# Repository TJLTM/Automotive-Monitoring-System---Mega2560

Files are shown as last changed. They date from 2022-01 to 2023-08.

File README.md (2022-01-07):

# Automotive-Monitoring-System---Mega2560
OpenSource monitoring system for older vehicles without OBDII. History for this project to give some insight in why i have it designed it as i have. My dad has a 1972 ford bronco that is used to go 4x4ing and it has since the day he bought it new over heated on trails while his friends 1970 stock bronco would be idling behind his vapor locked car on the trail. Mostly this is to solve that problem by providing data. Given data systems can be fixed. I based this on a MEGA2560 because of the number of I/O pins and real time nature of this. I may in the future switch this to SBC based but so far other than a few limitations has worked. 

What is logged: 
1. Fuel Pressure x 2
2. Tempetatures x 6
3. Manifold Vacuum x 2
4. AFR x 2
5. Battery Voltage
6. Current drawn from Alternator 
7. RPM 
8. Oil Pressure
9. GPS Data

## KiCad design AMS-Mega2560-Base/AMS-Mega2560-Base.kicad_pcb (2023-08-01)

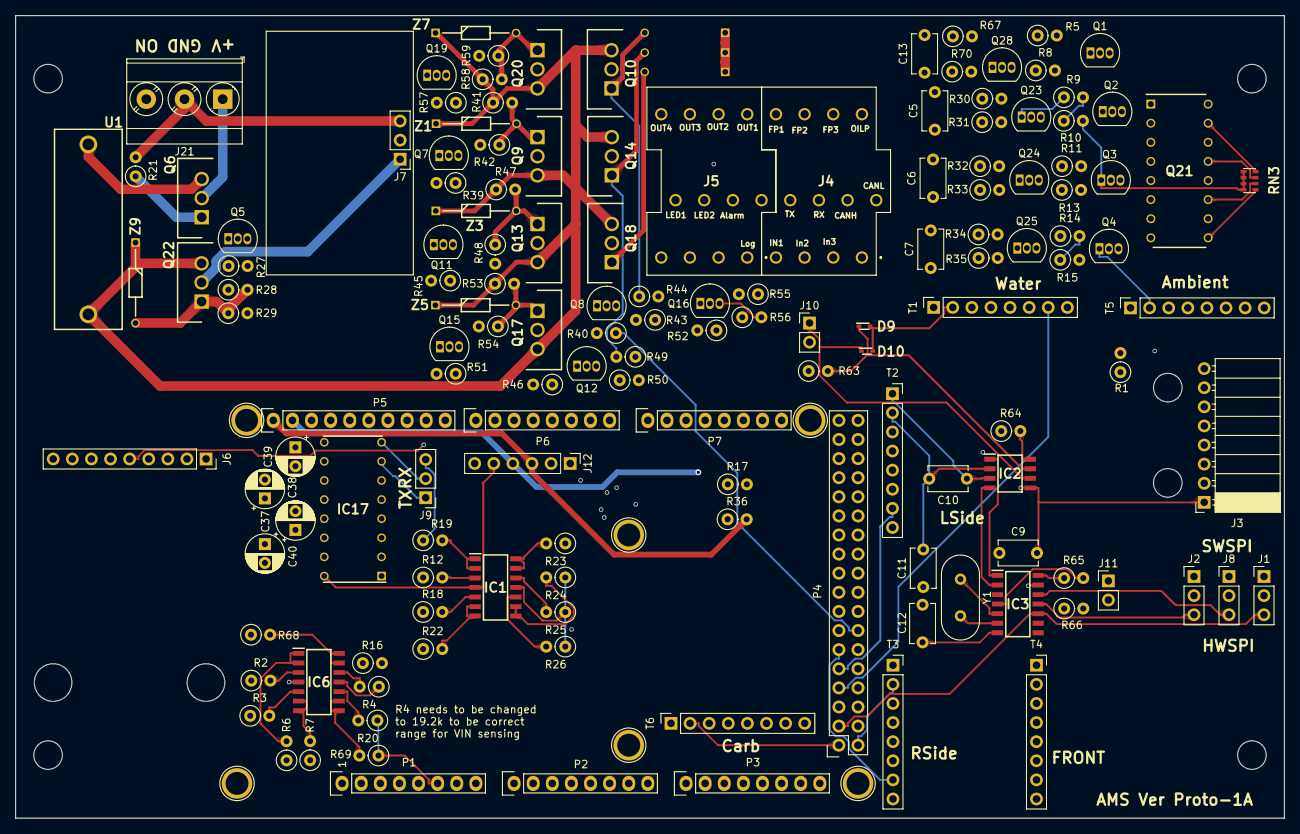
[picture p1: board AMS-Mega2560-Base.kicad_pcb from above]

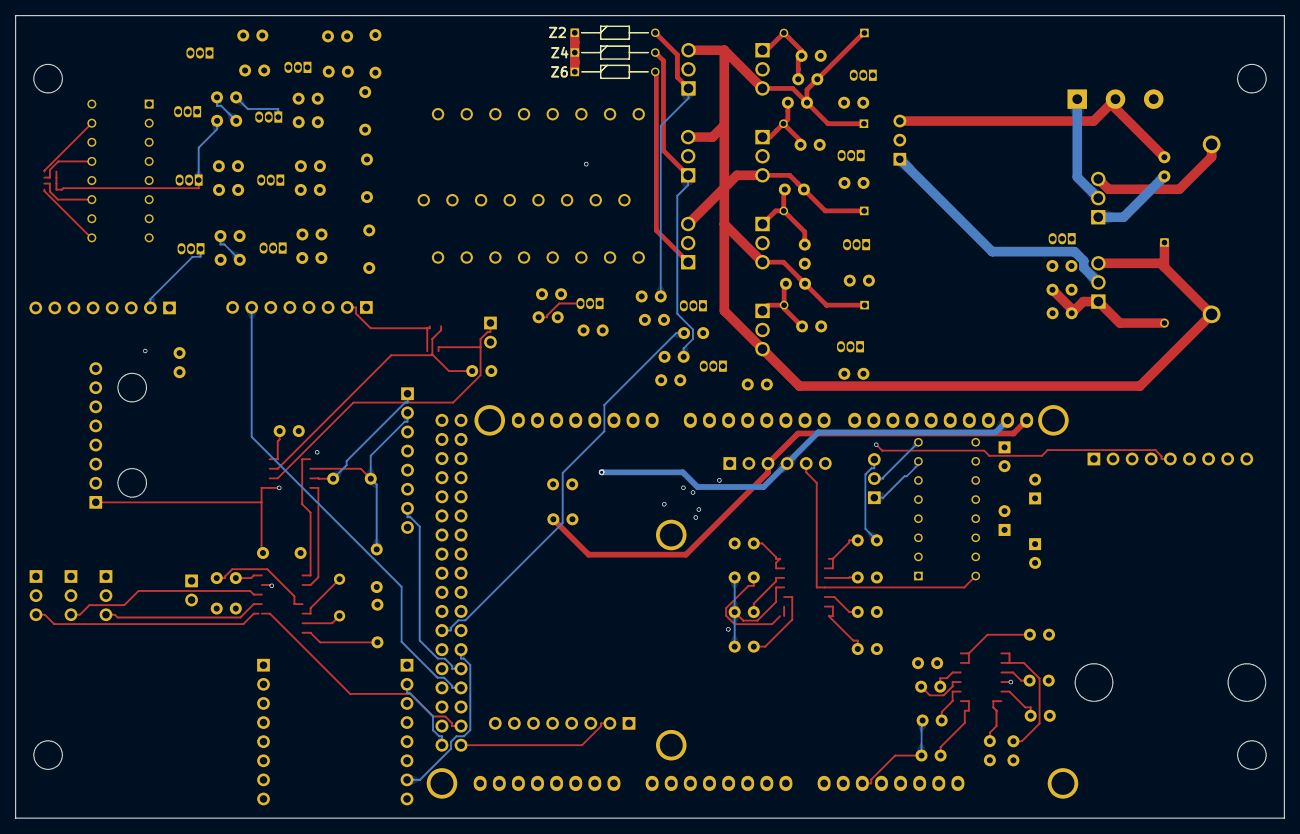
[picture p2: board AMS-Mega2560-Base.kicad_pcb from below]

Board: 4 copper layers, 168.7 x 106.7 mm, 153 parts (3 on the bottom side), 130 nets.

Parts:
C5, C6, C7, C13: 220nF; C_Disc_D5.1mm_W3.2mm_P5.00mm
C9: 0.1uF; C_Disc_D5.1mm_W3.2mm_P5.00mm
C10: 100nF; C_Disc_D5.1mm_W3.2mm_P5.00mm
C11, C12: 22pF; C_Disc_D5.1mm_W3.2mm_P5.00mm
C37, C38, C39, C40: 1uF; CP_Radial_D5.0mm_P2.50mm
D9, D10: ESD5Z5.0T1G; SODFL1608X70N
IC1, IC6: OPA4340UA; SOIC127P600X175-14N
IC2: MCP2542FD-H_SN; SOIC127P600X175-8N
IC3: MCP2518FDT-E_SL; SOIC127P600X175-14N
IC17: MAX232CPE+; DIP762W56P254L1918H457Q16N
J1, J2, J7, J8, J9: Conn_01x03; PinHeader_1x03_P2.54mm_Vertical
J3: Conn_01x08; PinSocket_1x08_P2.54mm_Horizontal
J4: Sense1; 1727751
J5: Sense2; 1727751
J6: AdafruitUltimateGPS; PinSocket_1x09_P2.54mm_Vertical
J10, J11: Conn_01x02; PinHeader_1x02_P2.54mm_Vertical
J12: Conn_01x06; PinHeader_1x06_P2.54mm_Vertical
J21: Screw_Terminal_01x03; TerminalBlock_Phoenix_MKDS-3-3-5.08_1x03_P5.08mm_Horizontal
P1: Power; Socket_Strip_Arduino_1x08
P2, P3: Analog; Socket_Strip_Arduino_1x08
P4: Digital; Socket_Strip_Arduino_2x18
P5: PWM; Socket_Strip_Arduino_1x10
P6: PWM; Socket_Strip_Arduino_1x08
P7: Communication; Socket_Strip_Arduino_1x08
P8, P9, P10, P11, P12, P13: CONN_01X01; Arduino_1pin
Q1, Q2, Q3, Q4, Q5, Q7, Q8, Q11, Q12, Q15, Q16, Q19: 2N7000; TO-92_Inline
Q6, Q9, Q10, Q13, Q14, Q17, Q18, Q20, Q22: IRF9Z34NPBF; TO254P469X1042X1967-3P
Q21: LTV-847; DIP762W60P254L1984H450Q16N
Q23, Q24, Q25, Q28: BS250; TO-92_Inline
R1, R6, R7, R19, R22, R23, R24, R68, R69: 47K; R_Axial_DIN0207_L6.3mm_D2.5mm_P2.54mm_Vertical
R2, R3, R4, R12, R18, R20, R25, R26: 100K; R_Axial_DIN0207_L6.3mm_D2.5mm_P2.54mm_Vertical
R5, R9, R11, R14: 470; R_Axial_DIN0207_L6.3mm_D2.5mm_P2.54mm_Vertical
R8, R10, R13, R15: 5k; R_Axial_DIN0207_L6.3mm_D2.5mm_P2.54mm_Vertical
R16, R65, R66: 47k; R_Axial_DIN0207_L6.3mm_D2.5mm_P2.54mm_Vertical
R17, R36: 2.2k; R_Axial_DIN0207_L6.3mm_D2.5mm_P2.54mm_Vertical
R21: 4.7K; R_Axial_DIN0207_L6.3mm_D2.5mm_P2.54mm_Vertical
R27, R28, R41, R43, R47, R49, R53, R55, R58: 100k; R_Axial_DIN0207_L6.3mm_D2.5mm_P2.54mm_Vertical
R29, R42, R44, R48, R50, R54, R56, R59, R64: 10k; R_Axial_DIN0207_L6.3mm_D2.5mm_P2.54mm_Vertical
R30, R32, R34, R67: 330; R_Axial_DIN0207_L6.3mm_D2.5mm_P2.54mm_Vertical
R31, R33, R35, R70: 1K; R_Axial_DIN0207_L6.3mm_D2.5mm_P2.54mm_Vertical
R39, R40, R45, R46, R51, R52, R57: 1M; R_Axial_DIN0207_L6.3mm_D2.5mm_P2.54mm_Vertical
R63: 120; R_Axial_DIN0207_L6.3mm_D2.5mm_P2.54mm_Vertical
RN3: EXB-38V223JV; EXB38V472JV
T1, T2, T3, T4, T5, T6: Conn_01x08; PinSocket_1x08_P2.54mm_Vertical
U1: BK_HTC-15M
Y1: Crystal; Crystal_HC49-U_Vertical
Z1, Z2, Z3, Z4, Z5, Z6, Z7, Z9: BZX79C10; DIOAD1068W53L380D172

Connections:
+5V: C9.2, C10.1, C40.2, IC1.4 (V+), IC2.3 (VDD), IC2.5 (VIO), IC3.14 (VDD), IC6.4 (V+), IC17.16 (VCC), J3.1, J6.8, J7.2, J12.5, P1.5, Q21.1 (ANODE_1), Q21.3 (ANODE_2), Q21.5 (ANODE_3), Q21.7 (ANODE_4), Q21.10 (COLLECTOR_1), Q21.12 (COLLECTOR_2), Q21.14 (COLLECTOR_3), Q21.16 (COLLECTOR_4), R1.1, R17.1, R36.1, R65.1, T1.1, T2.1, T3.1, T4.1, T5.1, T6.1
+VDC: Q9.3, Q10.3, Q13.3, Q14.3, Q17.3, Q18.3, Q20.3, Q22.3, R28.1, R41.1, R43.1, R47.1, R49.1, R53.1, R55.1, R58.1, U1.2, Z1.1, Z2.1, Z3.1, Z4.1, Z5.1, Z6.1, Z7.1, Z9.1
/BufferedADC1/ADCIN4: IC6.12 (+IN_D), R4.2, R16.2
/CAN Bus/CAN_INT: IC3.4 (~INT), J11.1, R65.2, R66.1
/Sheet6152913C/RSCOM2RX: IC17.8 (R2IN), J9.2
/Sheet6152913C/RSCOM2TX: IC17.7 (T2OUT), J9.1
AmbientCS: P4.15, T5.7
CANCS: IC3.13 (NCS), P4.23
CAN_INT: J11.2, P4.27
CAN_TX_STBY: IC2.8 (STBY), P4.25, R64.2
CarbCS: P4.17, T6.7
Com1RX: IC17.12 (R1OUT), P7.4
Com1TX: IC17.11 (T1IN), P7.3
Com2RX: IC17.9 (R2OUT), P7.6
Com2TX: IC17.10 (T2IN), P7.5
FrontCS: P4.13, T4.7
FuelPressure1: IC6.1 (OUT_A), IC6.2 (-IN_A), P2.3, R6.2
FuelPressure2: IC6.6 (-IN_B), IC6.7 (OUT_B), P2.4, R7.2
FuelPressure3: IC6.8 (OUT_C), IC6.9 (-IN_C), P2.5, R69.2
GND: C5.2, C6.2, C7.2, C9.1, C10.2, C11.2, C12.2, C13.2, C39.1, D9.2, D10.2, IC1.11 (V-), IC2.2 (VSS), IC3.7 (VSS), IC6.11 (V-), IC17.15 (GND), J3.3, J6.7, J7.3, J9.3, J12.6, J21.2, P1.6, P1.7, P4.1, P4.2, P5.4, Q1.1 (S), Q2.1 (S), Q3.1 (S), Q4.1 (S), Q5.1 (S), Q7.1 (S), Q8.1 (S), Q11.1 (S), Q12.1 (S), Q15.1 (S), Q16.1 (S), Q19.1 (S), R2.1, R3.1, R4.1, R6.1, R7.1, R8.2, R10.2, R12.1, R13.2, R15.2, R18.1, R19.1, R20.1, R21.2, R22.1, R23.1, R24.1, R25.1, R26.1, R27.2, R30.2, R32.2, R34.2, R39.2, R40.2, R45.2, R46.2, R51.2, R52.2, R57.2, R64.1, R66.2, R67.2, R68.1, R69.1, RN3.1, RN3.2, RN3.3, RN3.4, T1.2, T2.2, T3.2, T4.2, T5.2, T6.2
GPSBat: J6.3, P2.2
GPSRX: J6.6, P7.1
GPSTX: J6.5, P7.2
IN1TTL: P6.6, Q21.15 (EMITTER_4), RN3.8
IN2TTL: P6.5, Q21.13 (EMITTER_3), RN3.7
IN3TTL: P4.10, Q21.11 (EMITTER_2), RN3.6
Logging: P4.8, Q21.9 (EMITTER_1), RN3.5
LsideCS: P4.9, T2.7
MISO: IC3.11 (SDI), J2.3, J3.5, P4.5
MOSI: IC3.12 (SDO), J3.6, J8.3, P4.6
unnamed: J21.1, Q6.2
unnamed: Q6.3, U1.1
unnamed: C39.2, IC17.6 (V-)
unnamed: C40.1, IC17.2 (V+)
unnamed: IC2.4 (RXD), IC3.2 (RXCAN)
unnamed: IC2.1 (TXD), IC3.1 (TXCAN)
unnamed: C12.1, IC3.6 (OSC1), Y1.2
unnamed: C11.1, IC3.5 (OSC2), Y1.1
unnamed: C37.1, IC17.1 (C1+)
unnamed: C37.2, IC17.3 (C1-)
unnamed: C38.1, IC17.4 (C2+)
unnamed: C38.2, IC17.5 (C2-)
unnamed: J10.2, R63.1
unnamed: Q1.3 (D), R70.1
unnamed: Q1.2 (G), R5.2, R8.1
unnamed: Q2.3 (D), R31.1
unnamed: Q2.2 (G), R9.2, R10.1
unnamed: Q3.3 (D), R33.1
unnamed: Q3.2 (G), R11.2, R13.1
unnamed: Q4.3 (D), R35.1
unnamed: Q4.2 (G), R14.2, R15.1
unnamed: Q5.3 (D), R29.2
unnamed: Q6.1, R21.1
unnamed: Q7.3 (D), R42.2
unnamed: Q8.3 (D), R44.2
unnamed: Q9.1, R41.2, R42.1, Z1.2
unnamed: Q10.1, R43.2, R44.1, Z2.2
unnamed: Q11.3 (D), R48.2
unnamed: Q12.3 (D), R50.2
unnamed: Q13.1, R47.2, R48.1, Z3.2
unnamed: Q14.1, R49.2, R50.1, Z4.2
unnamed: Q15.3 (D), R54.2
unnamed: Q16.3 (D), R56.2
unnamed: Q17.1, R53.2, R54.1, Z5.2
unnamed: Q18.1, R55.2, R56.1, Z6.2
unnamed: Q19.3 (D), R59.2
unnamed: Q20.1, R58.2, R59.1, Z7.2
unnamed: Q21.2 (CATHODE_1), R70.2
unnamed: Q21.4 (CATHODE_2), R31.2
unnamed: Q21.6 (CATHODE_3), R33.2
unnamed: Q21.8 (CATHODE_4), R35.2
unnamed: Q22.1, R28.2, R29.1, Z9.2
unnamed: Q23.1 (D), R9.1
unnamed: Q23.2 (G), R30.1
unnamed: Q24.1 (D), R11.1
unnamed: Q24.2 (G), R32.1
unnamed: Q25.1 (D), R14.1
unnamed: Q25.2 (G), R34.1
unnamed: Q28.1 (D), R5.1
unnamed: Q28.2 (G), R67.1
OUTPUT1: P6.4, Q19.2 (G), R57.1
OUTPUT2: P6.3, Q7.2 (G), R39.1
OUTPUT3: P6.2, Q11.2 (G), R45.1
OUTPUT4: P6.1, Q15.2 (G), R51.1
OUTPUTLED1: P4.14, Q8.2 (G), R40.1
OUTPUTLED2: P4.12, Q12.2 (G), R46.1
OUTPUTSiren: P5.10, Q16.2 (G), R52.1
OilPressure: IC1.1 (OUT_A), IC1.2 (-IN_A), P2.6, R19.2
PowerOn: J21.3, Q5.2 (G), R27.1
RTDMISO: J2.2, T1.5, T2.5, T3.5, T4.5, T5.5, T6.5
RTDMOSI: J8.2, T1.6, T2.6, T3.6, T4.6, T5.6, T6.6
RTDSCLK: J1.2, T1.4, T2.4, T3.4, T4.4, T5.4, T6.4
RsideCS: P4.11, T3.7
SCL: J12.3, P5.1, P7.8, R36.2
SCLK: IC3.10 (SCK), J1.3, J3.4, P4.3
SDA: J12.4, P5.2, P7.7, R17.2
SDCS: J3.7, P4.19
SDDetect: J3.8, P4.21, R1.2
SWMISO: J2.1, P4.32
SWMOSI: J8.1, P4.34
SWSCLK: J1.1, P4.30
Sense1-1: J4.1, P3.2
Sense1-2: D10.1, IC2.6 (CANL), J4.2, J10.1
Sense1-3: IC1.3 (+IN_A), J4.3, R12.2
Sense1-4: C6.1, J4.4, Q24.3 (S)
Sense1-5: D9.1, IC2.7 (CANH), J4.5, R63.2
Sense1-6: IC6.10 (+IN_C), J4.6, R20.2
Sense1-7: C5.1, J4.7, Q23.3 (S)
Sense1-8: IC17.13 (R1IN), J4.8
Sense1-9: IC6.5 (+IN_B), J4.9, R3.2
Sense1-10: C13.1, J4.10, Q28.3 (S)
Sense1-11: IC17.14 (T1OUT), J4.11
Sense1-12: IC6.3 (+IN_A), J4.12, R2.2
Sense2-1: C7.1, J5.1, Q25.3 (S)
Sense2-3: J5.3, Q20.2
Sense2-4: IC1.12 (+IN_D), J5.4, R25.2
Sense2-5: J5.5, Q18.2
Sense2-6: J5.6, Q9.2
Sense2-7: IC1.10 (+IN_C), J5.7, R26.2
Sense2-8: J5.8, Q14.2
Sense2-9: J5.9, Q13.2
Sense2-10: IC1.5 (+IN_B), J5.10, R18.2
Sense2-11: J5.11, Q10.2
Sense2-12: J5.12, Q17.2
SpareADC1: IC1.6 (-IN_B), IC1.7 (OUT_B), P2.7, R22.2
SpareADC2: IC1.8 (OUT_C), IC1.9 (-IN_C), P2.8, R24.2
SpareADC3: IC1.13 (-IN_D), IC1.14 (OUT_D), P3.1, R23.2
VPP: J7.1, Q22.2, R16.1
VoltageSensor: IC6.13 (-IN_D), IC6.14 (OUT_D), P2.1, R68.2
WaterCS: P4.7, T1.7

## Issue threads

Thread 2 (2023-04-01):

Add CAN bus to thie base board.

TJLTM, 2023-04-01:
Add CAN bus to the base board to interface with regular car systems and to move some Sensors and other things offof the base board.

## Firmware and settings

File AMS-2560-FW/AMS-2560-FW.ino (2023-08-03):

#include <Wire.h>
#include <Adafruit_MAX31865.h>
#include <SPI.h>
#include <RTClib.h>
#include <EEPROM.h>


//-----------------------------------------------------------
// Serial Communication
//-----------------------------------------------------------
#define USBSerial Serial
#define RS232P1 Serial1
#define RS232P2 Serial2
char* AcceptedCommands[] = {"UNITS?", "DEVICE?", "BATTERY?", "RTCBATTERY?", "TEMPS?", "UNITTEMP?", "WARNING?",
                            "STREAMING?", "ALLDATA?", "UPDATEALL", "RESETWARNINGS", "RESETALLALARMS",
                            "TIME?", "REBOOT", "RESET", "STREAMINGONBOOT?", "STATUS?", "PORT?", "ALARM?"
                           };
char* ParameterCommands[] = {"SETUNITS", "SETSTREAMINGDATA", "SETTIME", "SETSTREAMINGONBOOT",
                            };
String inputString, inputStringRS232P1, inputStringRS232P2  = "";         // a String to hold incoming data from ports
bool stringComplete, stringCompleteRS232P1, stringCompleteRS232P2 = false;     // whether the string is complete for each respective port
//-----------------------------------------------------------
//-----------------------------------------------------------
// System Level
RTC_DS3231 rtc;
const String DeviceName = "AMS";
const String FWVersion = "0.0.1";
const float ConversionFactor = 5.0 / 1023;
bool WarningActive, AlarmActive = false;
int TotalWarnings = 7;
int ArrayOfWarnings[] = {};
long TempTimer, WarningBlinkTimer;
bool StreamingDataUSB, StreamingDataRS232 = false;
char Units;
String TempUnits, PressureUnits;
//-----------------------------------------------------------
/*
   All the Stored Values and Times to have states
   that can be recalled if streaming is turned off
*/
//Fuel Pressure
float LastFuel1, LastFuel2 = 0.0;
String LastTimeFuel = "";
//Battery Monitoring
float LastDCVoltage, LastGPSVoltage = 0.0;
String LastTimeDCVoltage, LastTimeGPSVoltage = "";
// Temps
String LastTimeTemp = "";
float LastCarbTemp, LastAmbientTemp, LastFrontOfEngineTemp, LastRightSideTemp, LastLeftSideTemp, LastWaterTemp = 0.0;
float LastRTCTemp = 0.0;
String LastTimeRTCTemp = "";
//-----------------------------------------------------------
//-----------------------------------------------------------
//RTD sensors
#define RTDWaterCS 48
#define RTDCarbCS 38
#define RTDAmbientCS 40
#define RTDLSCS 46
#define RTDRSCS 44
#define RTDFrontCS 42
#define RREF      430.0
#define RNOMINAL  100.0
Adafruit_MAX31865 RTDWater = Adafruit_MAX31865(RTDWaterCS);
Adafruit_MAX31865 RTDCarb = Adafruit_MAX31865(RTDCarbCS);
Adafruit_MAX31865 RTDAmbient = Adafruit_MAX31865(RTDAmbientCS);
Adafruit_MAX31865 RTDLS = Adafruit_MAX31865(RTDLSCS);
Adafruit_MAX31865 RTDRS = Adafruit_MAX31865(RTDRSCS);
Adafruit_MAX31865 RTDFront = Adafruit_MAX31865(RTDFrontCS);
//-----------------------------------------------------------
//-----------------------------------------------------------
//Alarm
#define AlarmOut 8
#define LED1 43
#define LED2 45
//-----------------------------------------------------------
//-----------------------------------------------------------
// Spare Inputs Outputs and Analog
#define LoggingInput 49
#define SpareInput1 2
#define SpareInput2 3
#define SpareInput3 47

#define SpareOutput1 4
#define SpareOutput2 5
#define SpareOutput3 6
#define SpareOutput4 7
//-----------------------------------------------------------
//-----------------------------------------------------------
// ADC Sensors
#define FuelPressure1Pin A2
#define FuelPressure2Pin A3
#define FuelPressure3Pin A4
#define VoltageSensorPin A0
#define OilPressurePin A5
#define GPSBattPin A1
#define SpareBufferedADC1Pin A6
#define SpareBufferedADC2Pin A7
#define SpareBufferedADC3Pin A8
#define SpareRAWADC1Pin A9
//-----------------------------------------------------------
//-----------------------------------------------------------
#define SDCardDetectPin 34
#define SDCS 36


void setup() {
  rtc.begin();
  RS232P1.begin(115200);
  RS232P2.begin(115200);
  USBSerial.begin(115200);
  inputString.reserve(100);
  inputStringRS232P1.reserve(100);
  inputStringRS232P2.reserve(100);

  pinMode(AlarmOut, OUTPUT);
  pinMode(LED1, OUTPUT);
  pinMode(LED2, OUTPUT);


  //RTD
  pinMode(RTDWaterCS, OUTPUT);
  pinMode(RTDCarbCS, OUTPUT);
  pinMode(RTDAmbientCS, OUTPUT);
  pinMode(RTDLSCS, OUTPUT);
  pinMode(RTDRSCS, OUTPUT);
  pinMode(RTDFrontCS, OUTPUT);
  /*
      Please Reference Adafruit_MAX31865
      docs for setup of these boards if
      you are going to use 4 or 2 wire
  */
  RTDWater.begin(MAX31865_3WIRE);
  RTDCarb.begin(MAX31865_3WIRE);
  RTDAmbient.begin(MAX31865_3WIRE);
  RTDLS.begin(MAX31865_3WIRE);
  RTDRS.begin(MAX31865_3WIRE);
  RTDFront.begin(MAX31865_3WIRE);

  //Energy
  //Load from EEProm

  //Load Streaming Setting from EEProm
  StreamingDataUSB = GetFromEEPROMStreamOnBootUSB();
  StreamingDataRS232 = GetFromEEPROMStreamOnBootRS232();

  //load system settings from EEProm

  //Set Warning Array up with -1 for being cleared.
  ResetWarnings();

  //Set up displays and output on the Serial Port
  BroadCast("Starting " + DeviceName);
  BroadCast("FW: " + FWVersion);
  Units = GetFromEEPROMUnits();
  SetUnitsForOutput();
  BroadCast("Units: " + String(Units));

  //Run through the sensors and get values for everything
  ForceCompleteUpdateOfAllStates();
  BroadCast("System Initialized and values populated:" + GetCurrentTime());
}

void loop() {

  /*
    Handle the Incoming commands from the Serial Ports
    after all the other operations have been done
  */
  if (stringComplete) {
    inputString = PainlessInstructionSet(inputString, 0);
    stringComplete = false;
  }

  serialRS232P1();
  if (stringCompleteRS232P1) {
    stringCompleteRS232P1 = PainlessInstructionSet(inputStringRS232P1, 1);
    stringCompleteRS232P1 = false;
  }

  serialRS232P2();
  if (stringCompleteRS232P2) {
    stringCompleteRS232P2 = PainlessInstructionSet(inputStringRS232P2, 1);
    stringCompleteRS232P2 = false;
  }

  SensorData();
}

void SensorData(){
  
}

void FuelPressure() {
  float FuelPressureDN1 = ReadAnalog(25, FuelPressure1Pin);
  float FuelPressureDN2 = ReadAnalog(25, FuelPressure2Pin);
  float FuelPressureDN3 = ReadAnalog(25, FuelPressure3Pin);

  //Sensors i'm using drop out at .5 volts and anything below that will show neg pressure. DN 102 translates to 0.5V
  if (FuelPressureDN1 > 102) {
    if (Units == 'I') {
      LastFuel1 = (7.5 * ConversionFactor * FuelPressureDN1) - 3.75;
      LastFuel2 = (7.5 * ConversionFactor * FuelPressureDN2) - 3.75;
    }
    else {
      LastFuel1 = ConvertPSItoKPa((7.5 * ConversionFactor * FuelPressureDN1) - 3.75);
      LastFuel2 = ConvertPSItoKPa((7.5 * ConversionFactor * FuelPressureDN2) - 3.75);
    }
  }
  else {
    LastFuel1, LastFuel2 = 0.0;
  }

  LastTimeFuel = GetCurrentTime();
}

void RTDSensors() {
  uint16_t rtd0 = RTDWater.readRTD();
  if (Units == 'I') {
    LastWaterTemp = ConvertCtoF(RTDWater.temperature(RNOMINAL, RREF));
  }
  else {
    LastWaterTemp = RTDWater.temperature(RNOMINAL, RREF);
  }

  uint16_t rtd1 = RTDCarb.readRTD();
  if (Units == 'I') {
    LastCarbTemp = ConvertCtoF(RTDCarb.temperature(RNOMINAL, RREF));
  }
  else {
    LastCarbTemp = RTDCarb.temperature(RNOMINAL, RREF);
  }

  uint16_t rtd2 = RTDAmbient.readRTD();
  if (Units == 'I') {
    LastAmbientTemp = ConvertCtoF(RTDAmbient.temperature(RNOMINAL, RREF));
  }
  else {
    LastAmbientTemp = RTDAmbient.temperature(RNOMINAL, RREF);
  }

  uint16_t rtd3 = RTDLS.readRTD();
  if (Units == 'I') {
    LastRightSideTemp = ConvertCtoF(RTDLS.temperature(RNOMINAL, RREF));
  }
  else {
    LastRightSideTemp = RTDLS.temperature(RNOMINAL, RREF);
  }

  uint16_t rtd4 = RTDLS.readRTD();
  if (Units == 'I') {
    LastLeftSideTemp = ConvertCtoF(RTDLS.temperature(RNOMINAL, RREF));
  }
  else {
    LastLeftSideTemp = RTDLS.temperature(RNOMINAL, RREF);
  }

  uint16_t rtd5 = RTDFront.readRTD();
  if (Units == 'I') {
    LastFrontOfEngineTemp = ConvertCtoF(RTDFront.temperature(RNOMINAL, RREF));
  }
  else {
    LastFrontOfEngineTemp = RTDFront.temperature(RNOMINAL, RREF);
  }

  LastTimeTemp = GetCurrentTime();
}


//------------------------------------------------------------------
//Other sensors
//------------------------------------------------------------------
void ReadBatteryVoltages() {
  float DCVoltageDN = ReadAnalog(50, VoltageSensorPin);
  float GPSVoltageDN = ReadAnalog(50, GPSBattPin);

  LastDCVoltage = 3.8 * ConversionFactor * DCVoltageDN - 1.2;
  LastTimeDCVoltage = GetCurrentTime();

  LastGPSVoltage = ConversionFactor * GPSVoltageDN;
  LastTimeGPSVoltage = LastTimeDCVoltage;

  if (LastDCVoltage < 10.5) {
    AddWarningToList(5);
  }

  if (LastGPSVoltage < 2.3) {
    AddWarningToList(1);
  }
}


//------------------------------------------------------------------
//EEPROM functions
//------------------------------------------------------------------
int GetFromEEPROMStreamOnBootUSB() {
  int Value = EEPROM.read(4);
  if (0 > Value || Value >= 2) {
    Value = 0;
    EEPROM.update(4, Value);
  }
  return Value;
}

int GetFromEEPROMStreamOnBootRS232() {
  int Value = EEPROM.read(5);
  if (0 > Value || Value >= 2) {
    Value = 0;
    EEPROM.update(5, Value);
  }
  return Value;
}

char GetFromEEPROMUnits() {
  char Value = EEPROM.read(0);
  if (Value != 'I' && Value != 'M') {
    Value = 'I';
    EEPROM.update(0, Value);
  }
  return Value;
}

//------------------------------------------------------------------
//Helper functions
//------------------------------------------------------------------
void(* resetFunc) (void) = 0;  // declare reset fuction at address 0

String StatesForOutput(int State) {
  String Value = "Off";
  if (State == 1) {
    Value = "On";
  }
  return Value;
}

void RebootDisBitch() {
  BroadCast("%R," + GetCurrentTime() + ",Rebooting");
  delay(2000);
  resetFunc();
}

void MIBFLASH() {
  BroadCast("%R," + GetCurrentTime() + ",Reseting wait for reboot Message");
  for (int i = 0 ; i < EEPROM.length() ; i++) {
    EEPROM.write(i, 0);
  }
  RebootDisBitch();
}

float ConvertCtoF(float C) {
  float F = (1.8 * C) + 32;
  return F;
}

float ConvertPSItoKPa(float PSI) {
  float KPA = 6.8947572932 * PSI;
  return KPA;
}

String GetCurrentTime() {
  DateTime now = rtc.now();

  char buf1[20];
  sprintf(buf1, "%02d:%02d:%02d-%02d/%02d/%02d",  now.hour(), now.minute(), now.second(), now.day(), now.month(), now.year());

  LastTimeRTCTemp = buf1;
  if (Units == 'I') {
    LastRTCTemp = ConvertCtoF(rtc.getTemperature());
  }
  else {
    LastRTCTemp = rtc.getTemperature();
  }
  return buf1;
}

String GetCurrentDate() {
  DateTime now = rtc.now();
  String CurrentDate = String(now.year()) + String(now.month()) + String(now.day());
  return CurrentDate;
}

void SetUnitsForOutput() {
  if (Units == "M") {
    TempUnits = "C";
    PressureUnits = "KPa";
  }
  else {
    TempUnits = "F";
    PressureUnits = "PSI";
  }
}

float ReadAnalog(int Samples, int PinNumber) {
  long Sum = 0;
  float Value = 0;
  for (int x = 0; x < Samples; x++) {
    Sum = Sum + analogRead(PinNumber);
  }
  Value = (Sum / Samples);
  return Value;
}

void PressureSensors() {
  int Samples = 50;
  long FuelSum = 0;
  long FuelSum1 = 0;
  long OilSum = 0;
  for (int x = 0; x < Samples; x++) {
    FuelSum = FuelSum + analogRead(FuelPressureSensorsPinAtCarb);
    FuelSum1 = FuelSum1 + analogRead(FuelPressureSensorsPinBeforeCooler);
    OilSum = OilSum + analogRead(OilPressureSensorsPin);
    
  }

  float FuelPSIatCarb = 1.2 * 7.5 * ConversionFactor * (FuelSum / Samples);
  float FuelPSIatPump = 1.2 * 7.5 * ConversionFactor * (FuelSum1 / Samples);
  float OilPSI = 25 * ConversionFactor * (OilSum / Samples) - 12.5;
  FuelPressureWarning(FuelPSIatCarb);

  
  float FuelPressure_carb = 0.0;
  float FuelPressure_pump = 0.0;
  float OilPressure = 0.0;
  String Units = "PSI";
  if (Units == "M") {
    FuelPressure_carb = ConvertPSItoKPa(FuelPSIatCarb);
    FuelPressure_pump = ConvertPSItoKPa(FuelPSIatPump);
    OilPressure = ConvertPSItoKPa(OilPSI);
    Units = "KPa";
  }
  else {
    FuelPressure_carb = FuelPSIatCarb;
    FuelPressure_pump = FuelPSIatPump;
    OilPressure = OilPSI;
  }

  LastFuelPatCarb = FuelPressure_carb;
  LastFuelPatPump = FuelPressure_pump;
  String LogEntry = "Units," + Units + ",Fuel At Carb," + String(FuelPressure_carb) + ",Fuel At pump," + String(FuelPressure_pump) + ",Oil," + String(OilPressure);
  AddLogEntry(0, "Pressure Sensors", LogEntry);
}

void ForceCompleteUpdateOfAllStates() {

  ReadBatteryVoltages();
}
//------------------------------------------------------------------
//Serial
//------------------------------------------------------------------
/*
  SerialEvent occurs whenever a new data comes in the hardware serial RX. This
  routine is run between each time loop() runs, so using delay inside loop can
  delay response. Multiple bytes of data may be available.
*/
void serialEvent() {
  while (USBSerial.available()) {
    // get the new byte:
    char inChar = (char)USBSerial.read();
    // add it to the inputString:
    inputString += inChar;
    // if the incoming character is a carriage return, set a flag so the main loop can
    // do something about it:
    if (inChar == '\r') {
      stringComplete = true;
    }
  }
}

void serialRS232P1() {
  while (RS232P1.available()) {
    // get the new byte:
    char inChar = (char)RS232P1.read();
    // add it to the inputString:
    inputStringRS232P1 += inChar;
    // if the incoming character is a carriage return, set a flag so the main loop can
    // do something about it:
    if (inChar == '\r') {
      stringCompleteRS232P1 = true;
    }
  }
}

void serialRS232P2() {
  while (RS232P2.available()) {
    // get the new byte:
    char inChar = (char)RS232P2.read();
    // add it to the inputString:
    inputStringRS232P2 += inChar;
    // if the incoming character is a carriage return, set a flag so the main loop can
    // do something about it:
    if (inChar == '\r') {
      stringCompleteRS232P2 = true;
    }
  }
}

void BroadCast(String Message) {
  SendItOut(Message, 0);
  SendItOut(Message, 1);
  SendItOut(Message, 2);
}

void CurrentSerialPort(int WhichPort) {
  if (WhichPort == 0) {
    USBSerial.println("%R,Current Port,USB");
  }
  if (WhichPort == 1) {
    RS232P1.println("%R,Current Port,USB");
  }
  if (WhichPort == 2) {
    RS232P2.println("%R,Current Port,USB");
  }

}

void SendItOut(String Message, int WhichPort) {
  if (WhichPort == 0) {
    USBSerial.println(Message);
  }
  if (WhichPort == 1) {
    RS232P1.println(Message);
  }
  if (WhichPort == 2) {
    RS232P2.println(Message);
  }
}

//------------------------------------------------------------------
//Serial Output
//------------------------------------------------------------------
void OutputAllData(int WhichPort) {
  GetDeviceInfo(WhichPort);
  GetSystemTime(WhichPort);
  AllWarningMessages(WhichPort);
  GetStreamingState(WhichPort);
  GetUnits(WhichPort);
  GetDCBatteryVoltage(WhichPort);
  GetRTCBatteryVotlage(WhichPort);
  GetHeadUnitTemp(WhichPort);
  GetStreamingOnBoot(WhichPort);
  GetStreamingState(WhichPort);
}

void OutputLiveData(int WhichPort) {
  GetDCBatteryVoltage(WhichPort);
  GetRTCBatteryVotlage(WhichPort);
  GetHeadUnitTemp(WhichPort);
  GetStreamingOnBoot(WhichPort);
  GetStreamingState(WhichPort);
}

void GetDCBatteryVoltage(int WhichPort) {
  SendItOut("%R," + LastTimeDCVoltage + ",VDC," + LastDCVoltage, WhichPort);
}

void GetRTCBatteryVotlage(int WhichPort) {
  SendItOut("%R," + LastTimeRTCVoltage + ",RTCBattery," + LastRTCVoltage, WhichPort);
}

void GetHeadUnitTemp(int WhichPort) {
  SendItOut("%R," + LastTimeRTCTemp + ",Head Unit Temp,Units," + TempUnits + "," + LastRTCTemp, WhichPort);
}

void GetUnits(int WhichPort) {
  SendItOut("%R,Units," + String(Units), WhichPort);
}

void GetDeviceInfo(int WhichPort) {
  SendItOut("%R," + DeviceName + "," + FWVersion, WhichPort);
}

void GetStreamingState(int WhichPort) {
  SendItOut("%R,StreamingData,USB," + StatesForOutput(StreamingDataUSB) + ",RS232," +
            StatesForOutput(StreamingDataRS232) , WhichPort);
}

void GetSystemTime(int WhichPort) {
  SendItOut("%R,System Time," + GetCurrentTime(), WhichPort);
}

void GetStreamingOnBoot(int WhichPort) {
  SendItOut("%R,Streaming Data on boot,USB," + StatesForOutput(GetFromEEPROMStreamOnBootUSB()) + ",RS232," +
            StatesForOutput(GetFromEEPROMStreamOnBootRS232()) , WhichPort);
}

void GetAlarmStatus(int WhichPort) {
  String Message = "%R," + GetCurrentTime() + ",ALARM,Cleared";
  if (AlarmActive == true) {
    Message = "%R," + GetCurrentTime() + ",ALARM,Active";
  }
  SendItOut(Message, WhichPort);
}

void GetTemps(int WhichPort) {
  SendItOut("%R,Temps,Units," + "" + ",Water," + String(LastWaterTemp) + ",," + String(LastCarbTemp) + ",," + String(LastAmbientTemp) , WhichPort);
}
//------------------------------------------------------------------
//Alarm and Warnings
//------------------------------------------------------------------
void Error(int Number, int WhichPort) {
  const char* Errors[] = {"command not recognized", "command Parameter out of range", "command not supported on this platform",
                          "command can not be processed", "Invalid Parameter", "Invalid Command Format"
                         };
  SendItOut("%R,Error," + String(Errors[Number]), WhichPort);
}

void Warning() {
  if (WarningActive == true) {
    if (abs(millis() - WarningBlinkTimer) >  333) {
      WarningBlinkTimer = millis();
      if (digitalRead(WarningLED) == LOW) {
        digitalWrite(WarningLED, HIGH);
      } else {
        digitalWrite(WarningLED, LOW);
      }
    }
  }
}

void AddWarningToList(int WarningID) {
  WarningActive = true;
  if (ArrayOfWarnings[WarningID] != WarningID) {
    ArrayOfWarnings[WarningID] = WarningID;
    OutputWarningMessage(WarningID);
  }
}

void OutputWarningMessage(int ID) {
  if (ArrayOfWarnings[ID] != 0) {
    String Message = "";
    switch (ID) {
      case 1:
        Message = "RTC Battery voltage is low";
        break;
      case 2:
        Message = "One of the holding tanks is getting full";
        break;
      case 3:
        Message = "";
        break;
      case 4:
        Message = "";
        break;
      case 5:
        Message = "Battery voltage is low";
        break;
      case 6:
        Message = "";
        break;
      case 7:
        Message = "";
        break;
    }
    BroadCast("%R,Warning," + Message);
  }
}

void AllWarningMessages(int WhichPort) {
  if (WarningActive == true) {
    for (int i = 1; i <= TotalWarnings; i++) {
      if (ArrayOfWarnings[i] != -1) {
        OutputWarningMessage(i);
        WarningActive = true;
      }
    }
  }
  else {
    SendItOut("%R,Warning,Clear", WhichPort);
  }
}

void ALARM() {
  digitalWrite(AlarmOut, HIGH);
  AlarmActive = true;
  GetAlarmStatus(0);
  GetAlarmStatus(1);
  GetAlarmStatus(2);
}

void ResetAlarm() {
  digitalWrite(AlarmOut, LOW);
  if (AlarmActive == true) {
    AlarmActive = false;
    GetAlarmStatus(0);
    GetAlarmStatus(1);
  }
}

void ResetWarnings() {
  for (int i = 1; i <= TotalWarnings; i++) {
    ArrayOfWarnings[i] = -1;
  }
  WarningActive = false;
  digitalWrite(WarningLED, LOW);
}

void ResetAllAlarmsAndWarnings() {
  ResetAlarm();
  ResetWarnings();
}
//------------------------------------------------------------------
//Commands
//------------------------------------------------------------------
void SetUnits(String Value, int WhichPort) {
  char CurrentUnits = Units;
  int Index = Value.indexOf("*");
  int End = Value.indexOf("\r");
  String ThingToTest = Value.substring(Index + 1, End - 1);
  if (ThingToTest.length() == 1) {
    bool CorrectParam = false;
    if (ThingToTest == "I") {
      Units = 'I';
      CorrectParam = true;
    }
    if (ThingToTest == "M") {
      Units = 'M';
      CorrectParam = true;
    }
    if (CorrectParam == true) {
      EEPROM.update(0, Units);
      GetUnits(WhichPort);
      if (CurrentUnits != Units) {
        ForceCompleteUpdateOfAllStates();
      }
    }
    else {
      Error(4, WhichPort);
    }
  }
  else {
    Error(1, WhichPort);
  }
  SetUnitsForOutput();
}

void SetStreamingData(String Value, int WhoToSet, int WhichPort) {
  int Index = Value.indexOf("*");
  int End = Value.indexOf("\r");
  String Start = Value.substring(Index + 1, End - 1);
  int SecondParam = Start.indexOf("*");
  String SerialPortName  = Start.substring(0, SecondParam);
  String State = Start.substring(SecondParam + 1, End - 1);
  bool CorrectParam = false;
  if (SerialPortName == "USB") {
    if (State == "OFF") {
      if (WhoToSet == 1) {
        EEPROM.update(4, 0);
      }
      StreamingDataUSB = false;
      CorrectParam = true;
    }
    if (State == "ON") {
      if (WhoToSet == 1) {
        EEPROM.update(4, 1);
      }
      StreamingDataUSB = true;
      CorrectParam = true;
    }
  }

  if (SerialPortName == "RS232") {
    if (State == "OFF") {
      if (WhoToSet == 1) {
        EEPROM.update(5, 0);
      }
      StreamingDataRS232 = false;
      CorrectParam = true;
    }
    if (State == "ON") {
      if (WhoToSet == 1) {
        EEPROM.update(5, 1);
      }
      StreamingDataRS232 = true;
      CorrectParam = true;
    }
  }

  if (CorrectParam == true) {
    if (WhoToSet == 1) {
      GetStreamingOnBoot(WhichPort);
    }
    GetStreamingState(WhichPort);
  }
  else {
    Error(4, WhichPort);
  }
}
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

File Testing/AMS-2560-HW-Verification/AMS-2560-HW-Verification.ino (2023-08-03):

#include <Wire.h>
#include <Adafruit_MAX31865.h>
#include <SPI.h>
#include <RTClib.h>


//-----------------------------------------------------------
// Serial Communication
//-----------------------------------------------------------
#define USBSerial Serial
#define RS232P1 Serial1
#define RS232P2 Serial2

String inputStringP1 = "";         // a String to hold incoming data
bool stringCompleteP1 = false;  // whether the string is complete
String inputStringP2 = "";         // a String to hold incoming data
bool stringCompleteP2 = false;  // whether the string is complete

//-----------------------------------------------------------
//-----------------------------------------------------------
// System Level
RTC_DS3231 rtc;
const float ConversionFactor = 5.0 / 1023;
//RTD sensors
#define RTDWaterCS 48
#define RTDCarbCS 38
#define RTDAmbientCS 40
#define RTDLSCS 46
#define RTDRSCS 44
#define RTDFrontCS 42
#define RREF      430.0
#define RNOMINAL  100.0
Adafruit_MAX31865 RTDWater = Adafruit_MAX31865(RTDWaterCS);
Adafruit_MAX31865 RTDCarb = Adafruit_MAX31865(RTDCarbCS);
Adafruit_MAX31865 RTDAmbient = Adafruit_MAX31865(RTDAmbientCS);
Adafruit_MAX31865 RTDLS = Adafruit_MAX31865(RTDLSCS);
Adafruit_MAX31865 RTDRS = Adafruit_MAX31865(RTDRSCS);
Adafruit_MAX31865 RTDFront = Adafruit_MAX31865(RTDFrontCS);
//-----------------------------------------------------------
//-----------------------------------------------------------
//Alarm
#define AlarmOut 8
#define LED1 43
#define LED2 45
//-----------------------------------------------------------
//-----------------------------------------------------------
// Spare Inputs Outputs and Analog
#define LoggingInput 49
#define SpareInput1 2
#define SpareInput2 3
#define SpareInput3 47

#define SpareOutput1 4
#define SpareOutput2 5
#define SpareOutput3 6
#define SpareOutput4 7
//-----------------------------------------------------------
//-----------------------------------------------------------
// ADC Sensors
#define FuelPressure1Pin A2
#define FuelPressure2Pin A3
#define FuelPressure3Pin A4
#define VoltageSensorPin A0
#define OilPressurePin A5
#define GPSBattPin A1
#define SpareBufferedADC1Pin A6
#define SpareBufferedADC2Pin A7
#define SpareBufferedADC3Pin A8
#define SpareRAWADC1Pin A9
//-----------------------------------------------------------
//-----------------------------------------------------------
#define SDCardDetectPin 34
#define SDCS 36

void setup() {
  rtc.begin();
  
  // reserve 200 bytes for the inputString:
  inputStringP1.reserve(200);
  inputStringP2.reserve(200);
  
  RS232P1.begin(115200);
  RS232P2.begin(115200);
  USBSerial.begin(115200);

  pinMode(AlarmOut, OUTPUT);
  pinMode(LED1, OUTPUT);
  pinMode(LED2, OUTPUT);

  pinMode(SpareInput1, INPUT);
  pinMode(SpareInput2, INPUT);
  pinMode(SpareInput3, INPUT);
  pinMode(LoggingInput, INPUT);

  pinMode(SDCardDetectPin, INPUT);

  //RTD
  pinMode(RTDWaterCS, OUTPUT);
  pinMode(RTDCarbCS, OUTPUT);
  pinMode(RTDAmbientCS, OUTPUT);
  pinMode(RTDLSCS, OUTPUT);
  pinMode(RTDRSCS, OUTPUT);
  pinMode(RTDFrontCS, OUTPUT);
  /*
      Please Reference Adafruit_MAX31865
      docs for setup of these boards if
      you are going to use 4 or 2 wire
  */
  RTDWater.begin(MAX31865_3WIRE);
  RTDCarb.begin(MAX31865_3WIRE);
  RTDAmbient.begin(MAX31865_3WIRE);
  RTDLS.begin(MAX31865_3WIRE);
  RTDRS.begin(MAX31865_3WIRE);
  RTDFront.begin(MAX31865_3WIRE);

  pinMode(SpareInput1, INPUT);
  pinMode(SpareInput2, INPUT);
  pinMode(SpareInput3, INPUT);
  pinMode(SpareOutput1, OUTPUT);
  pinMode(SpareOutput2, OUTPUT);
  pinMode(SpareOutput3, OUTPUT);
  pinMode(SpareOutput4, OUTPUT);
}

void loop() {
  OutputTesting();
  InputTesting();
  OilPressureTesting();
  FuelPressureTesting();
  VoltageSensorTesting();
  SpareADCTestin();
  SDCardTesting();
  GPSBatTesting();
  SerialTestingP1();
  SerialTestingP2();
}

void SerialTestingP1(){
    // print the string when a newline arrives:
  if (stringCompleteP1) {
    RS232P1.println(inputStringP1);
    // clear the string:
    inputStringP1 = "";
    stringCompleteP1 = false;
  }
  serialEventP1();
}

void serialEventP1() {
  while (RS232P1.available()) {
    // get the new byte:
    char inChar = (char)RS232P1.read();
    // add it to the inputString:
    inputStringP1 += inChar;
    // if the incoming character is a newline, set a flag so the main loop can
    // do something about it:
    if (inChar == '\n') {
      stringCompleteP1 = true;
    }
  }
}

void SerialTestingP2(){
    // print the string when a newline arrives:
  if (stringCompleteP2) {
    RS232P2.println(inputStringP2);
    // clear the string:
    inputStringP2 = "";
    stringCompleteP2 = false;
  }
  serialEventP2();
}

void serialEventP2() {
  while (RS232P2.available()) {
    // get the new byte:
    char inChar = (char)RS232P2.read();
    // add it to the inputString:
    inputStringP2 += inChar;
    // if the incoming character is a newline, set a flag so the main loop can
    // do something about it:
    if (inChar == '\n') {
      stringCompleteP2 = true;
    }
  }
}

void OutputTesting() {
  Serial.println("Turned ON:LED1");
  digitalWrite(LED1, HIGH);
  delay(2500);
  Serial.println("Turned Off:LED1");
  digitalWrite(LED1, LOW);
  delay(5000);

  Serial.println("Turned ON:LED2");
  digitalWrite(LED2, HIGH);
  delay(2500);
  Serial.println("Turned Off:LED2");
  digitalWrite(LED2, LOW);
  delay(5000);

  Serial.println("Turned ON:Alarm");
  digitalWrite(AlarmOut, HIGH);
  delay(2500);
  Serial.println("Turned Off:Alarm");
  digitalWrite(AlarmOut, LOW);
  delay(5000);

  Serial.println("Turned ON:OUT1");
  digitalWrite(SpareOutput1, HIGH);
  delay(2500);
  Serial.println("Turned Off:OUT1");
  digitalWrite(SpareOutput1, LOW);
  delay(5000);

  Serial.println("Turned ON:OUT2");
  digitalWrite(SpareOutput2, HIGH);
  delay(2500);
  Serial.println("Turned Off:OUT2");
  digitalWrite(SpareOutput2, LOW);
  delay(5000);

  Serial.println("Turned ON:OUT3");
  digitalWrite(SpareOutput3, HIGH);
  delay(2500);
  Serial.println("Turned Off:OUT3");
  digitalWrite(SpareOutput3, LOW);
  delay(5000);

  Serial.println("Turned ON:OUT4");
  digitalWrite(SpareOutput4, HIGH);
  delay(2500);
  Serial.println("Turned Off:OUT4");
  digitalWrite(SpareOutput4, LOW);
  delay(5000);
}

void InputTesting() {
  // These are inverted Logic 0=On 1=Off
  //SOrry not enough room to put an inverter
  Serial.print("INPUT1:");
  Serial.println(digitalRead(SpareInput1));
  delay(2500);

  Serial.print("INPUT2:");
  Serial.println(digitalRead(SpareInput2));
  delay(2500);

  Serial.print("INPUT3:");
  Serial.println(digitalRead(SpareInput3));
  delay(2500);

  Serial.print("Logging:");
  Serial.println(digitalRead(LoggingInput));
  delay(2500);
}

float ReadAnalog(int Samples, int PinNumber) {
  long Sum = 0;
  float Value = 0;
  for (int x = 0; x < Samples; x++) {
    Sum = Sum + analogRead(PinNumber);
  }
  Value = (Sum / Samples);
  return Value;
}
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

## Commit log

2021-08-16 initial blank kicad project
    [AMS-Mega2560-Base.kicad_pcb, AMS-Mega2560-Base.sch]
2021-09-22 mostly done. I need to double check the SDcard circuit design and verify that it will work. also i need to route to the term blocks for the RTDs
    [AMS-Mega2560-Base.kicad_pcb, file613F8E12.sch, file614516B7.sch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]
2021-09-26 fixing some fuck ups in the hierarchical sheets and deleted some unused ref
    [AMS-Mega2560-Base.sch, file614516B7.sch, file614F8DF4.sch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]
2021-09-26 still fixing the schematic the coms/RTC need to assign footprints and double check all the parts in that file.
    [file6152913C.sch, file61534325.sch]
2021-09-26 fixed the schematics for the RTC, IO and COMs. Realigned the RTD to screw term. need to finish the 3.3v portion of the power systems.
    [AMS-Mega2560-Base.kicad_pcb, AMS-Mega2560-Base.sch, file61493C0D.sch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]
2021-10-05 wip working on it.
    [file61493C0D.sch]
2021-10-08 rearranging some of the hw design before i rename the repo.
    [AMS-Mega2560-Base.kicad_pcb, AMS-Mega2560-Base.sch, file613F8E12.sch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]
2022-01-07 upgrading this to 6.0 and moving the vacuum sensors to a daughter board project.
    [AMS-Mega2560-Base.kicad_pcb, AMS-Mega2560-Base.kicad_sch, AMS-Mega2560-Base.sch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]
2022-01-07 fixing some library settings and updating some schematics
    [AMS-Mega2560-Base.kicad_pcb, AMS-Mega2560-Base.kicad_sch, AMS-Vacuum-Sensor.kicad_pcb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]
2022-01-09 BaseBoard fixes and updates. doing schematic work.
    [AMS-Mega2560-Base.kicad_pcb, AMS-Mega2560-Base.kicad_sch, file613F8E12.kicad_sch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]
2022-01-10 trying to fix the PCB layout.
    [AMS-Mega2560-Base.kicad_pcb, AMS-Mega2560-Base.kicad_sch, file613F8E12.kicad_sch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]
2022-01-10 rollback and file clean up.
    [AMS-Mega2560-Base.kicad_pcb, AMS-Mega2560-Base.kicad_sch, AMS-Mega2560-Base.sch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]
2022-01-10 fixed the messed up references and cleaned up the schematic.
    [AMS-Mega2560-Base.kicad_pcb, AMS-Mega2560-Base.kicad_sch, file61493C0D.kicad_sch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]
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2022-01-12 wip for the base PCB, finished Vacuum PCB and Fab Files for that.
    [AMS-Mega2560-Base.kicad_pcb, AMS-Mega2560-Base.kicad_sch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]
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2022-01-15 moving the Vacuum sensor daughter board to the vacuum sensor project.
    [AMS-Vacuum-Sensor-B_Cu.gbr, AMS-Vacuum-Sensor-B_Mask.gbr, AMS-Vacuum-Sensor-B_Paste.gbr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]
2022-02-01 wip adding the throttle position sensor input stuff.
    [AMS-Mega2560-Base.kicad_pcb, AMS-Mega2560-Base.kicad_sch]
2022-02-05 slowly working on getting the board laid out and updates to some of the schematics.
    [AMS-Mega2560-Base.kicad_pcb, AMS-Mega2560-Base.kicad_sch, file61493C0D.kicad_sch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]
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2022-02-08 I think everything is placed on the board special routes have been done. need to finish routing everything else.
    [AMS-Mega2560-Base.kicad_pcb, AMS-Mega2560-Base.kicad_sch, file6152913C.kicad_sch]
2022-02-13 WIP for power on input and RTC battery switch over.
    [AMS-Mega2560-Base.kicad_pcb, AMS-Mega2560-Base.kicad_sch, file613F8E12.kicad_sch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]
2022-02-14 moving some things around on the board to clear the Vacuum board.
    [AMS-Mega2560-Base.kicad_pcb]
2022-02-22 fixing the 5V lines and removing the 5V fromt he MCU board and only using the 3Amp 5v power supplied by CampKeen
    [AMS-Mega2560-Base.kicad_sch, file61493C0D.kicad_sch, file6152913C.kicad_sch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]
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2022-02-22 still fixing ERC stuff
    [AMS-Mega2560-Base.kicad_sch, file613F8E12.kicad_sch]
2022-02-22 cleared all of the ERC stuff need to go over some of the power stuff for this before finishing routing.
    [AMS-Mega2560-Base.kicad_sch, Outputs.kicad_sch, file613F8E12.kicad_sch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]
2022-02-22 Schematic ERC is done and DRC for current layout is done. Need to verify a new part of the circuit before routing the rest of the board.
    [AMS-Mega2560-Base.kicad_pcb]
2022-02-23 pushing this change to the repo need to vet some schematics
    [AMS-Mega2560-Base.kicad_pcb, AMS-Mega2560-Base.kicad_sch, file61493C0D.kicad_sch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]
2022-02-24 adding some fixes for the RPM sensor and trying to fit everything on the board. WIp for FW
    [AMS-Mega2560-Base.kicad_pcb, AMS-Mega2560-Base.kicad_sch, file614CA8F2.kicad_sch]
2022-02-25 adding the buffered adcs to this. before splitting the project due to lack of chips.
    [BufferedADC.kicad_sch]
2022-02-25 adding lack of chips project where i have to replace the RTD with Dev boards
    [AMS-Mega2560-Base-Lack-Of-Chips.kicad_pcb, AMS-Mega2560-Base-Lack-Of-Chips.kicad_sch, BufferedADC.kicad_sch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]
2022-02-25 replaced the RTD with adafruit Dev boards which are easy to get at the moment.
    [AMS-Mega2560-Base-Lack-Of-Chips.kicad_sch, BufferedADC.kicad_sch, file614CA8F2.kicad_sch]
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2022-02-28 removing this as it's not needed in this design anymore
    [file61534325.kicad_sch]
2022-02-28 removing separate project for lack of chips and switching to dev boards. copied out the schematics used.
    [AMS-Mega2560-Base-Lack-Of-Chips.kicad_pcb, AMS-Mega2560-Base-Lack-Of-Chips.kicad_sch, AMS-Mega2560-Base.kicad_sch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]
2022-02-28 orphaned sheets until a can get the correct chips
    [3voltlogicshifter.kicad_sch, Max31865AAP+.kicad_sch, Vacuum Design.kicad_sch]
2022-03-23 applying some fixes for the RPM sensor and other parts of the schem
    [AMS-Mega2560-Base.kicad_pcb, AMS-Mega2560-Base.kicad_sch, BufferedADC.kicad_sch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]
2022-03-28 updated a few things for the SPI lines to the RTDs ready for routing.
    [AMS-Mega2560-Base.kicad_pcb, AMS-Mega2560-Base.kicad_sch, BufferedADC.kicad_sch]
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2022-04-06 routed and DRC'ed. almost ready to send off to be Fabbed.
    [AMS-Mega2560-Base.kicad_pcb]
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2022-05-29 updated SD Card Detect resistor to be 47k vs 50k
    [AMS-Mega2560-Base.kicad_pcb, AMS-Mega2560-Base.kicad_sch, BufferedADC.kicad_sch]
2022-06-01 updating some values and footprints. needs to have the routing tweaked
    [AMS-Mega2560-Base.kicad_pcb, AMS-Mega2560-Base.kicad_sch, BufferedADC.kicad_sch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]
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2022-06-24 working on fixing the screw ups. adding a second serial port
    [AMS-Mega2560-Base.kicad_sch, BufferedADC.kicad_sch, file6152913C.kicad_sch]
2022-06-27 still working on the base code. updating some of the HW stuff
    [AMS-Mega2560-Base.kicad_pcb, AMS-Mega2560-Base.kicad_sch, file6152913C.kicad_sch]
2022-07-03 fixing software SPI
    [AMS-Mega2560-Base.kicad_sch, BufferedADC.kicad_sch]
2022-07-04 working on the verification code while i test what is f-ing wrong with this hardware
    [AMS-2560-HW-Verification.ino]
2022-07-05 fixed all the bad merges.
    [AMS-2560-HW-Verification.ino]
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2022-07-06 * Swapped RX/TX for the GPS * added pull down resistors on buffered ADCs * Removed pot on SpareBufferedADC
    [AMS-Mega2560-Base.kicad_sch, BufferedADC.kicad_sch]
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2022-07-09 wip for adding second rs232 port. needs to have the other end added to an output pin/port
    [AMS-Mega2560-Base.kicad_sch, file6152913C.kicad_sch]
2022-07-13 still working on the fixes.
    [AMS-Mega2560-Base.kicad_pcb, file61493C0D.kicad_sch]
2022-07-14 just need to route the 5V power around the board before i figure out what to do with the other serial port
    [AMS-Mega2560-Base.kicad_pcb]
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2022-07-15 fixed 2.5v source. added gnd fill area to keep the noise down.
    [AMS-Mega2560-Base.kicad_pcb, BufferedADC.kicad_sch, file61493C0D.kicad_sch]
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2022-07-15 autorouted needs to be DRC'ed and fix whatever the autorouter did horribly
    [AMS-Mega2560-Base.kicad_pcb]
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2022-07-17 changing SMD footprint for RPM sensor CAP reDRC'ed and remade the FAB files
    [AMS-Mega2560-Base.kicad_pcb, AMS-Mega2560-Base.kicad_sch, BufferedADC.kicad_sch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]
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2022-08-10 fixed footprint and synced schem and layout
    [AMS-Mega2560-Base.kicad_pcb, AMS-Mega2560-Base.kicad_sch, BufferedADC.kicad_sch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]
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2023-06-11 finished CAN section. inputs need to be fixed.
    [AMS-Mega2560-Base.kicad_sch, CANBus.kicad_sch]
2023-07-14 * Schematic ** finished CAN bus Design work ** updated the input circuits to my standard design and removed the old one that was funky
    * PCB
    ** updated footprints
    ** removed the old parts/designed
    ** starting prep for placing parts
    [AMS-Mega2560-Base.kicad_pcb, AMS-Mega2560-Base.kicad_sch, CANBus.kicad_sch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]
2023-07-31 * got parts placed * modified the Input circuit design to include Nchannel fet Needs the tricky routes done before doing autoroute
    [AMS-Mega2560-Base.kicad_pcb, AMS-Mega2560-Base.kicad_sch, file6153A78F.kicad_sch]
2023-08-01 added I2C pullup resistors DRCed and fixed everything Pre Routing. Routed some of the basics. all parts are placed on the board. Pre Autoreouting.
    [AMS-Mega2560-Base.kicad_pcb, AMS-Mega2560-Base.kicad_sch]
2023-08-01 Fab Files updated Added PCBway Zip updating ibom.html Sending this off to Fab.
    [AMS-Mega2560-Base-B_Adhesive.gbr, AMS-Mega2560-Base-B_Cu.gbr, AMS-Mega2560-Base-B_Mask.gbr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]
2023-08-03 fixed the hardware verification stuff. working on updating the FW for this since it's a mismash of CampKeen and The OG AMS
    [AMS-2560-FW.ino, AMS-2560-HW-Verification.ino]
